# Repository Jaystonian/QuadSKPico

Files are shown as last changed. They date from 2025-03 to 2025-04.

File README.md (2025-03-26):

# **README - QuadSKPico (Open-Source SID Emulation Hardware)**

## **About This Project**

QuadSKpico is an open-source hardware design for a **multi-RP2040-based SID chip emulator**. It is built from the ground up, independent of SIDKick, and aims to provide a **fully open alternative** for C64 audio enthusiasts.

## **Why This Project?**

- **Truly open-source**: Unlike other designs, all schematics and PCB layouts are **fully published**.
- **Expandable & Community-Driven**: Encourages modifications, improvements, and innovations.
- **No artificial restrictions**: Anyone can build, improve, and even sell hardware based on this design.

## **License & Usage**

- This hardware is licensed under the **CERN OHL-S 2.0**, ensuring it remains open and free.
- The firmware it runs is released under **GPLv3**, meaning modifications must also remain open-source.
- This project is **not affiliated with or derived from SIDKick hardware** and the SIDKick Pico software is not compatible.

## **How to Contribute**

Pull requests, hardware modifications, and software contributions are welcome! Feel free to fork, improve, and share your work.

## **Credits**

- Hardware Designed by **JAYSTONIAN**
- Inspired by the open-source hardware movement and the SID emulation community.

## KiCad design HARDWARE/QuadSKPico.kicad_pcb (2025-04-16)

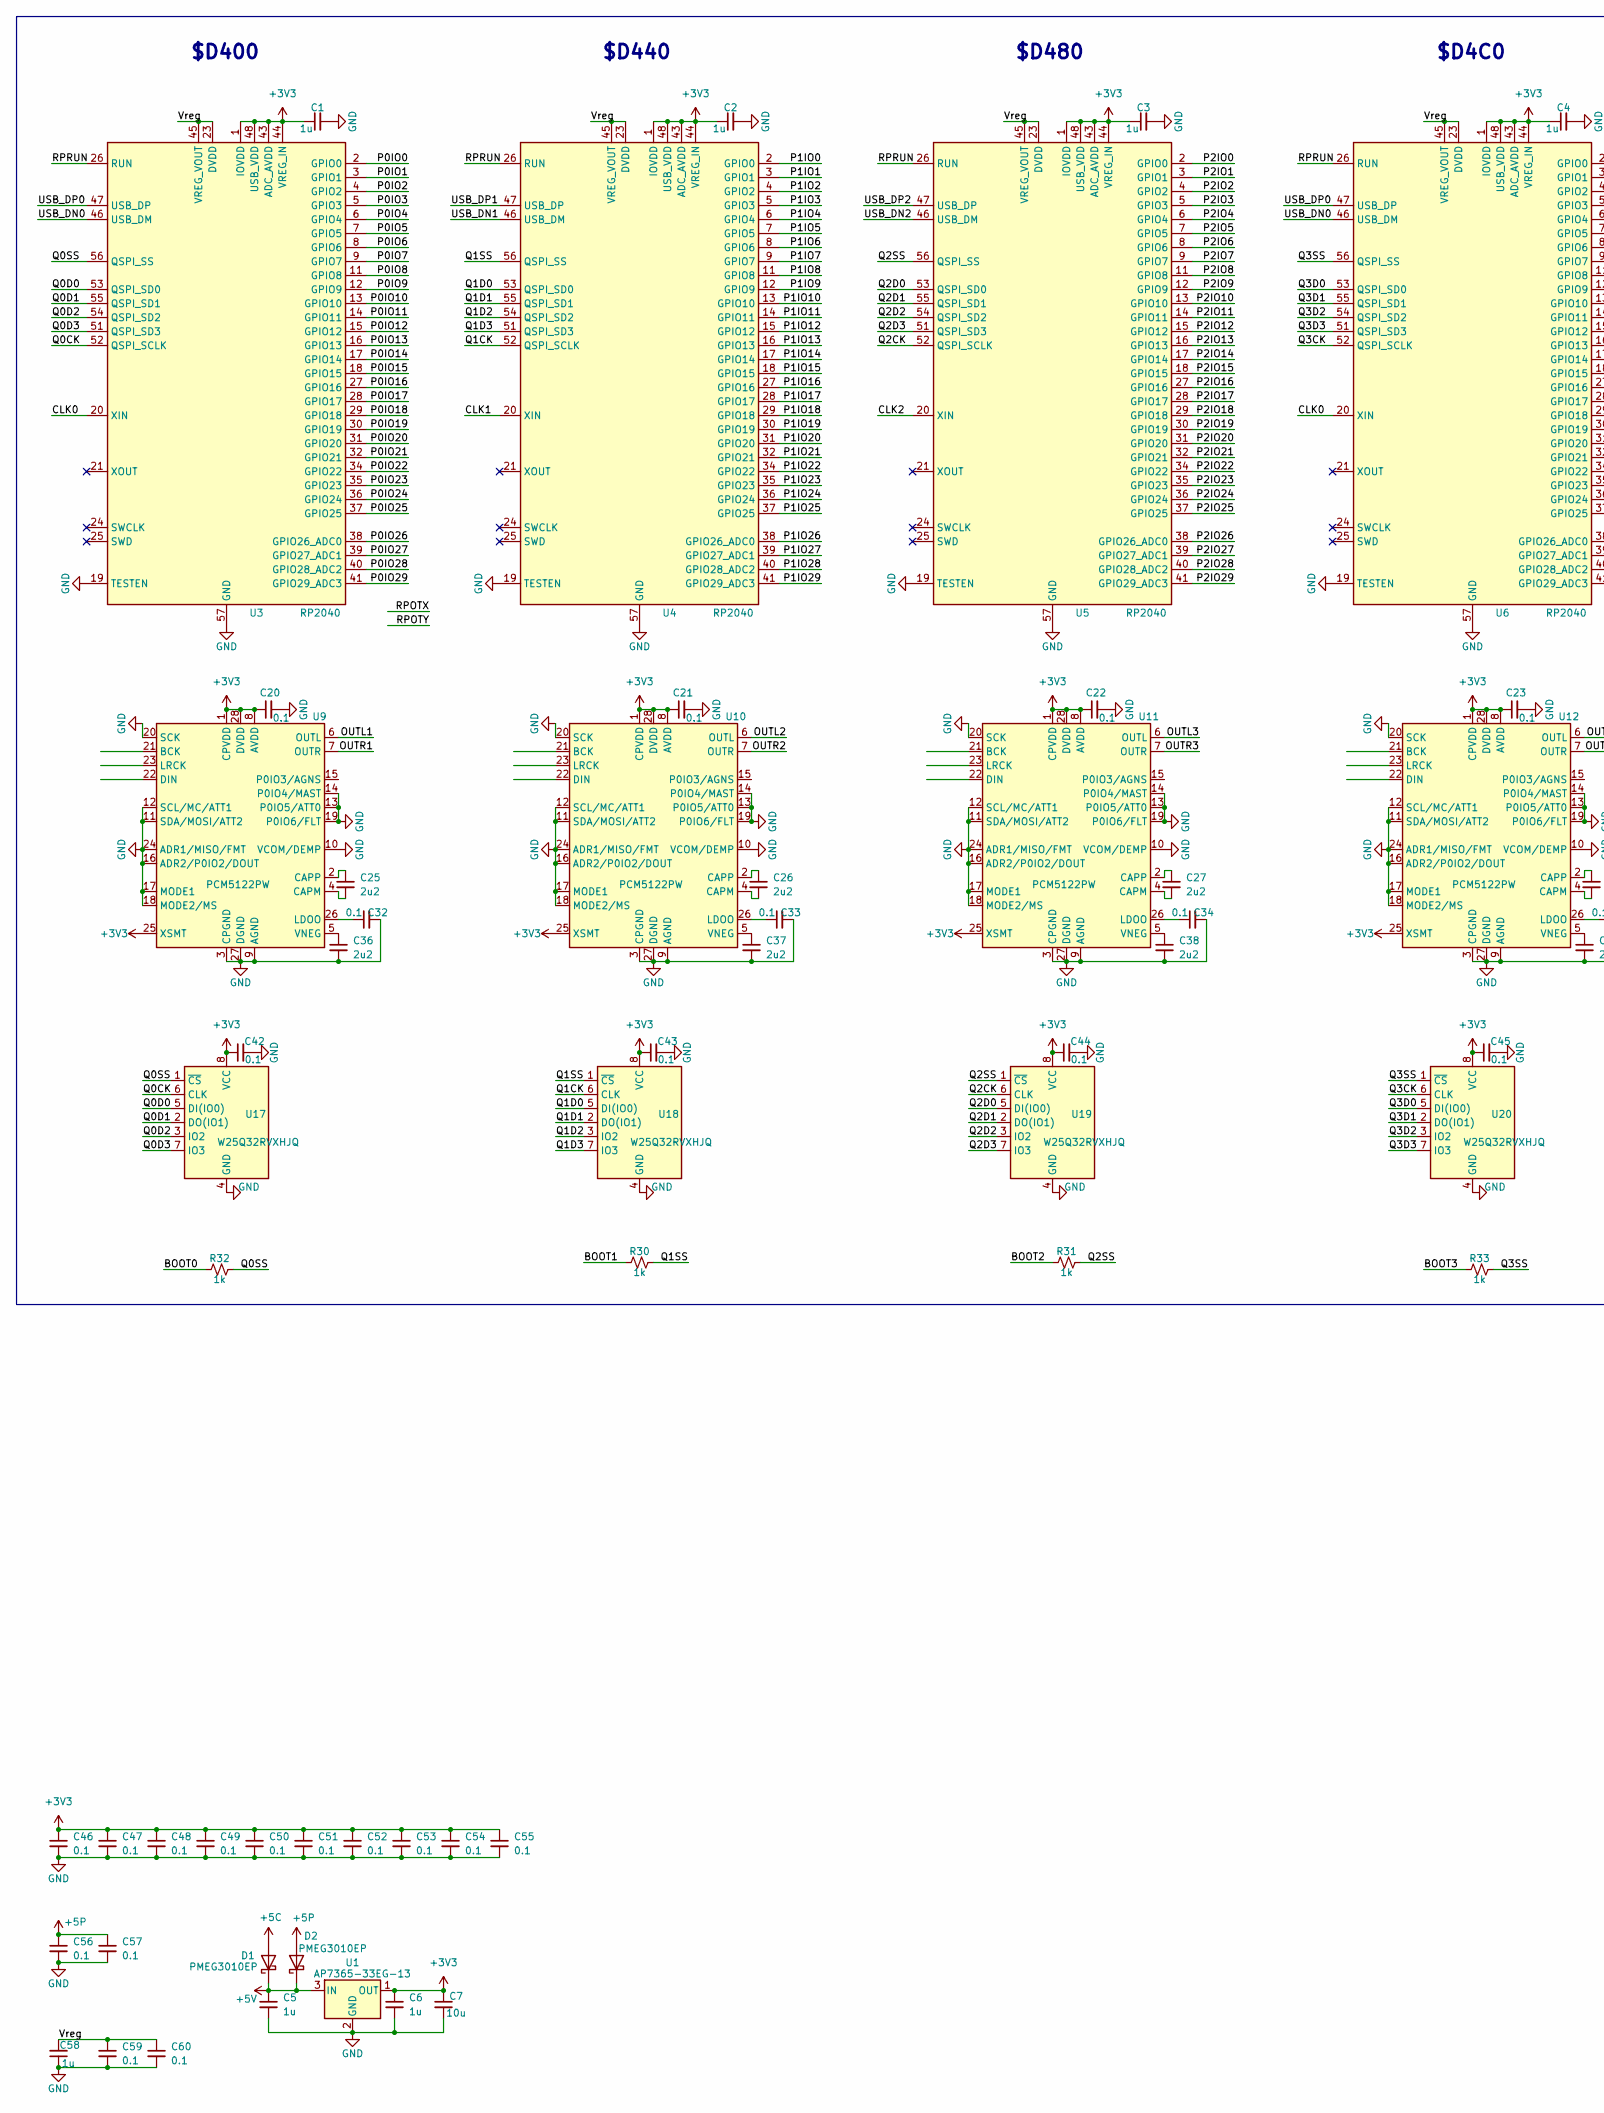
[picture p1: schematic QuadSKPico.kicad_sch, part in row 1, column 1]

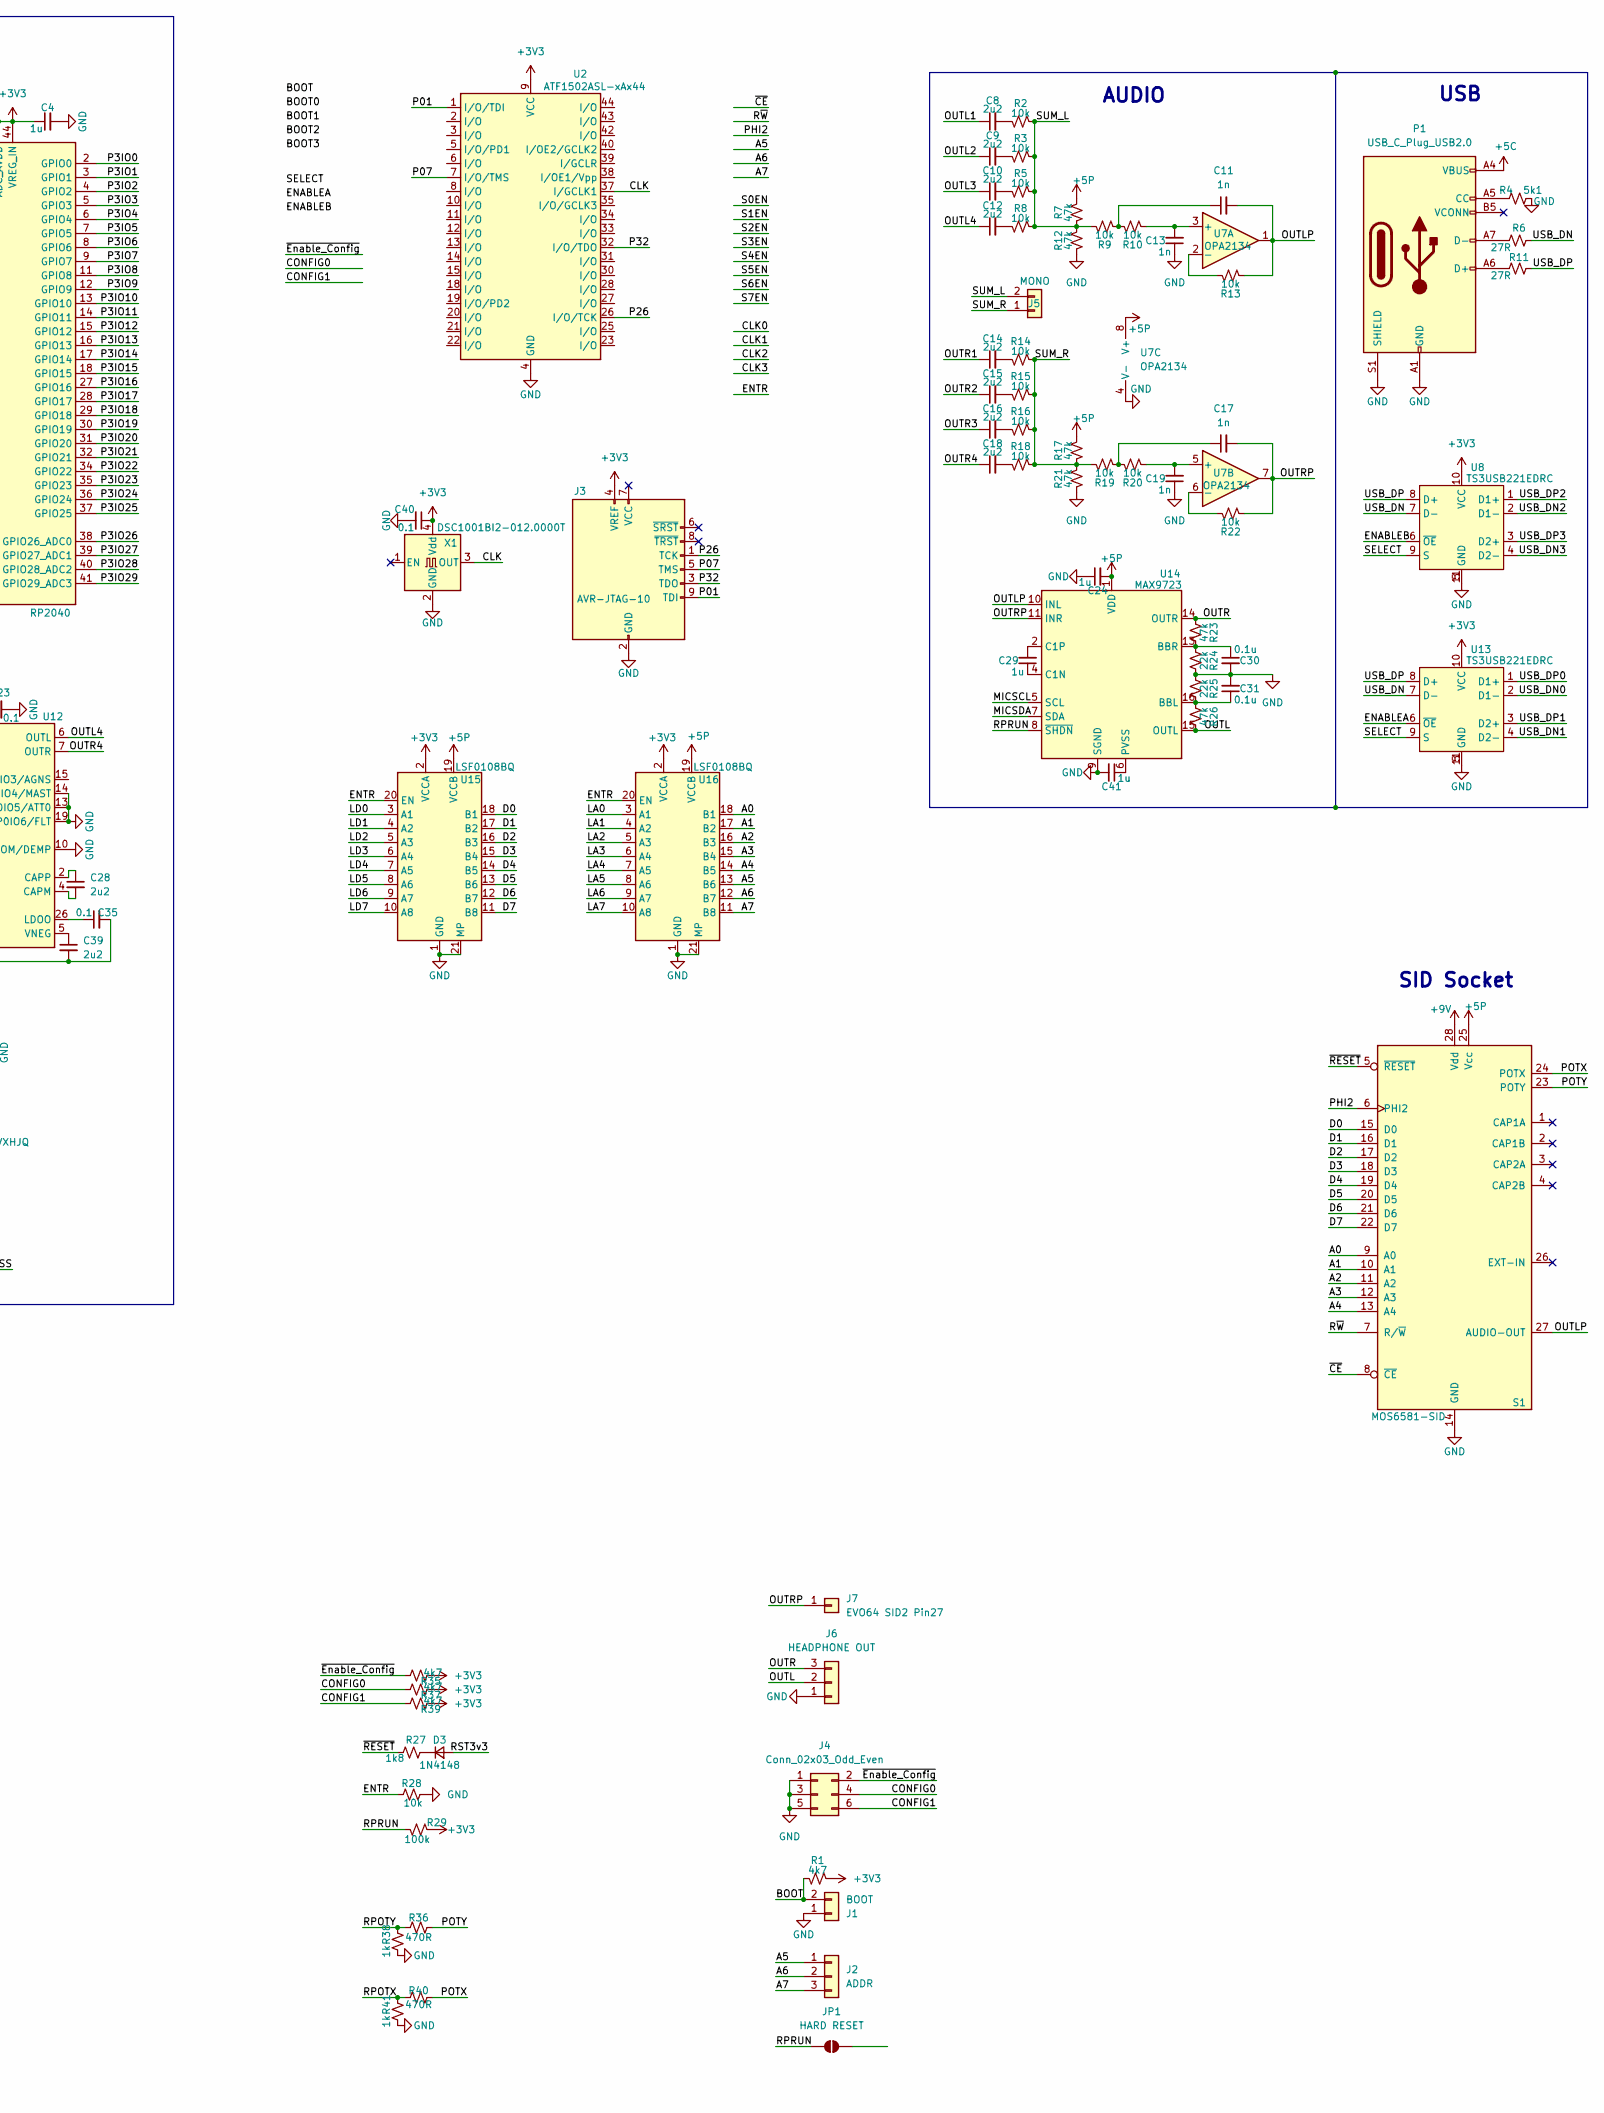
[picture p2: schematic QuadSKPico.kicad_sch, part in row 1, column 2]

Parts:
C1, C2, C3, C4, C5, C6, C24, C29, C41, C58: 1u; C_0805_2012Metric_Pad1.18x1.45mm_HandSolder
C7: 10u; C_0805_2012Metric_Pad1.18x1.45mm_HandSolder
C8, C9, C10, C12, C14, C15, C16, C18, C25, C26, C27, C28, C36, C37, C38, C39: 2u2; C_0805_2012Metric_Pad1.18x1.45mm_HandSolder
C11, C13, C17, C19: 1n; C_0805_2012Metric_Pad1.18x1.45mm_HandSolder
C20, C21, C22, C23, C32, C33, C34, C35, C40, C42, C43, C44, C45, C46, C47, C48, C49, C50, C51, C52, C53, C54, C55, C56, C57, C59, C60: 0.1; C_0805_2012Metric_Pad1.18x1.45mm_HandSolder
C30, C31: 0.1u; C_0805_2012Metric_Pad1.18x1.45mm_HandSolder
D1, D2: PMEG3010EP; D_SMA_Handsoldering
D3: 1N4148; D_MiniMELF
J1: BOOT; PinHeader_1x02_P2.54mm_Vertical
J2: ADDR; PinHeader_1x03_P2.54mm_Vertical
J3: AVR-JTAG-10; PinHeader_2x05_P2.54mm_Vertical
J4: Conn_02x03_Odd_Even; PinHeader_2x03_P2.54mm_Vertical
J5: MONO; PinHeader_1x02_P2.54mm_Vertical
J6: HEADPHONE OUT; PinHeader_1x03_P2.54mm_Vertical
J7: EVO64 SID2 Pin27; PinHeader_1x01_P2.54mm_Vertical
JP1: HARD RESET; SolderJumper-2_P1.3mm_Open_RoundedPad1.0x1.5mm
P1: USB_C_Plug_USB2.0; USB_C_Receptacle_GCT_USB4110
R1, R35, R37, R39: 4k7; C_0805_2012Metric_Pad1.18x1.45mm_HandSolder
R2, R3, R5, R8, R9, R10, R13, R14, R15, R16, R18, R19, R20, R22, R28: 10k; C_0805_2012Metric_Pad1.18x1.45mm_HandSolder
R4: 5k1; C_0805_2012Metric_Pad1.18x1.45mm_HandSolder
R6, R11: 27R; C_0805_2012Metric_Pad1.18x1.45mm_HandSolder
R7, R12, R17, R21, R23, R26: 47k; C_0805_2012Metric_Pad1.18x1.45mm_HandSolder
R24, R25: 22k; C_0805_2012Metric_Pad1.18x1.45mm_HandSolder
R27: 1k8; C_0805_2012Metric_Pad1.18x1.45mm_HandSolder
R29: 100k; C_0805_2012Metric_Pad1.18x1.45mm_HandSolder
R30, R31, R32, R33, R38, R41: 1k; C_0805_2012Metric_Pad1.18x1.45mm_HandSolder
R36, R40: 470R; C_0805_2012Metric_Pad1.18x1.45mm_HandSolder
S1: MOS6581-SID; DIP-28_W15.24mm_Socket
U1: AP7365-33EG-13; SOT-223-3_TabPin2
U2: ATF1502ASL-xAx44; TQFP-44_10x10mm_P0.8mm
U3, U4, U5, U6: RP2040; QFN-56-1EP_7x7mm_P0.4mm_EP3.2x3.2mm
U7: OPA2134; SOIC-8_3.9x4.9mm_P1.27mm
U8, U13: TS3USB221EDRC; VSON-10-1EP_3x3mm_P0.5mm_EP1.65x2.4mm_ThermalVias
U9, U10, U11, U12: PCM5122PW; TSSOP-28_4.4x9.7mm_P0.65mm
U14: MAX9723; TQFN-16-1EP_4x4mm_P0.65mm_EP2.1x2.1mm_ThermalVias
U15, U16: LSF0108BQ; DHVQFN-20-1EP_2.5x4.5mm_P0.5mm_EP1x3mm
U17, U18, U19, U20: W25Q32RVXHJQ; Winbond_USON-8-1EP_3x2mm_P0.5mm_EP0.2x1.6mm
X1: DSC1001BI2-012.0000T; Oscillator_SMD_TXC_7C-4Pin_5.0x3.2mm

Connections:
+3V3: C1.1, C2.1, C3.1, C4.1, C6.1, C7.1, C20.1, C21.1, C22.1, C23.1, C40.1, C42.1, C43.1, C44.1, C45.1, C46.1, C47.1, C48.1, C49.1, C50.1, C51.1, C52.1, C53.1, C54.1, C55.1, J3.4 (VREF), R1.1, R29.1, R35.1, R37.1, R39.1, U1.1 (OUT), U2.9 (VCC), U2.17 (VCC), U2.29 (VCC), U2.41 (VCC), U3.1 (IOVDD), U3.10 (IOVDD), U3.22 (IOVDD), U3.33 (IOVDD), U3.42 (IOVDD), U3.43 (ADC_AVDD), U3.44 (VREG_IN), U3.48 (USB_VDD), U3.49 (IOVDD), U4.1 (IOVDD), U4.10 (IOVDD), U4.22 (IOVDD), U4.33 (IOVDD), U4.42 (IOVDD), U4.43 (ADC_AVDD), U4.44 (VREG_IN), U4.48 (USB_VDD), U4.49 (IOVDD), U5.1 (IOVDD), U5.10 (IOVDD), U5.22 (IOVDD), U5.33 (IOVDD), U5.42 (IOVDD), U5.43 (ADC_AVDD), U5.44 (VREG_IN), U5.48 (USB_VDD), U5.49 (IOVDD), U6.1 (IOVDD), U6.10 (IOVDD), U6.22 (IOVDD), U6.33 (IOVDD), U6.42 (IOVDD), U6.43 (ADC_AVDD), U6.44 (VREG_IN), U6.48 (USB_VDD), U6.49 (IOVDD), U8.10 (VCC), U9.1 (CPVDD), U9.8 (AVDD), U9.25 (XSMT), U9.28 (DVDD), U10.1 (CPVDD), U10.8 (AVDD), U10.25 (XSMT), U10.28 (DVDD), U11.1 (CPVDD), U11.8 (AVDD), U11.25 (XSMT), U11.28 (DVDD), U12.1 (CPVDD), U12.8 (AVDD), U12.25 (XSMT), U12.28 (DVDD), U13.10 (VCC), U15.2 (VCCA), U16.2 (VCCA), U17.8 (VCC), U18.8 (VCC), U19.8 (VCC), U20.8 (VCC), X1.4 (Vdd)
+5C: D1.2 (A), P1.A4 (VBUS), P1.A9 (VBUS), P1.B4 (VBUS), P1.B9 (VBUS)
+5P: C24.2, C56.1, C57.1, D2.2 (A), R7.1, R17.1, S1.25 (Vcc), U7.8 (V+), U14.1 (VDD), U15.19 (VCCB), U16.19 (VCCB)
+5V: C5.1, D1.1 (K), D2.1 (K), U1.3 (IN)
+9V: S1.28 (Vdd)
/A0: S1.9 (A0), U16.18 (B1)
/A1: S1.10 (A1), U16.17 (B2)
/A2: S1.11 (A2), U16.16 (B3)
/A3: S1.12 (A3), U16.15 (B4)
/A4: S1.13 (A4), U16.14 (B5)
/A5: J2.1, U16.13 (B6)
/A6: J2.2, U16.12 (B7)
/A7: J2.3, U16.11 (B8)
/BOOT: J1.2, R1.2
/BOOT0: R32.1
/BOOT1: R30.1
/BOOT2: R31.1
/BOOT3: R33.1
/CLK: U2.37 (I/GCLK1), X1.3 (OUT)
/CLK0: U3.20 (XIN), U6.20 (XIN)
/CLK1: U4.20 (XIN)
/CLK2: U5.20 (XIN)
/CONFIG0: J4.4, R37.2
/CONFIG1: J4.6, R39.2
/D0: S1.15 (D0), U15.18 (B1)
/D1: S1.16 (D1), U15.17 (B2)
/D2: S1.17 (D2), U15.16 (B3)
/D3: S1.18 (D3), U15.15 (B4)
/D4: S1.19 (D4), U15.14 (B5)
/D5: S1.20 (D5), U15.13 (B6)
/D6: S1.21 (D6), U15.12 (B7)
/D7: S1.22 (D7), U15.11 (B8)
/ENABLEA: U13.6 (~OE)
/ENABLEB: U8.6 (~OE)
/ENTR: R28.1, U15.20 (EN), U16.20 (EN)
/LA0: U16.3 (A1)
/LA1: U16.4 (A2)
/LA2: U16.5 (A3)
/LA3: U16.6 (A4)
/LA4: U16.7 (A5)
/LA5: U16.8 (A6)
/LA6: U16.9 (A7)
/LA7: U16.10 (A8)
/LD0: U15.3 (A1)
/LD1: U15.4 (A2)
/LD2: U15.5 (A3)
/LD3: U15.6 (A4)
/LD4: U15.7 (A5)
/LD5: U15.8 (A6)
/LD6: U15.9 (A7)
/LD7: U15.10 (A8)
/MICSCL: U14.5 (SCL)
/MICSDA: U14.7 (SDA)
/OUTL: J6.2, R26.2, U14.15 (OUTL)
/OUTL1: C8.1, U9.6 (OUTL)
/OUTL2: C9.1, U10.6 (OUTL)
/OUTL3: C10.1, U11.6 (OUTL)
/OUTL4: C12.1, U12.6 (OUTL)
/OUTLP: C11.2, R13.2, S1.27 (AUDIO-OUT), U7.1, U14.10 (INL)
/OUTR: J6.3, R23.1, U14.14 (OUTR)
/OUTR1: C14.1, U9.7 (OUTR)
/OUTR2: C15.1, U10.7 (OUTR)
/OUTR3: C16.1, U11.7 (OUTR)
/OUTR4: C18.1, U12.7 (OUTR)
/OUTRP: C17.2, J7.1, R22.2, U7.7, U14.11 (INR)
/P0IO0: U3.2 (GPIO0)
/P0IO1: U3.3 (GPIO1)
/P0IO2: U3.4 (GPIO2)
/P0IO3: U3.5 (GPIO3)
/P0IO4: U3.6 (GPIO4)
/P0IO5: U3.7 (GPIO5)
/P0IO6: U3.8 (GPIO6)
/P0IO7: U3.9 (GPIO7)
/P0IO8: U3.11 (GPIO8)
/P0IO9: U3.12 (GPIO9)
/P0IO10: U3.13 (GPIO10)
/P0IO11: U3.14 (GPIO11)
/P0IO12: U3.15 (GPIO12)
/P0IO13: U3.16 (GPIO13)
/P0IO14: U3.17 (GPIO14)
/P0IO15: U3.18 (GPIO15)
/P0IO16: U3.27 (GPIO16)
/P0IO17: U3.28 (GPIO17)
/P0IO18: U3.29 (GPIO18)
/P0IO19: U3.30 (GPIO19)
/P0IO20: U3.31 (GPIO20)
/P0IO21: U3.32 (GPIO21)
/P0IO22: U3.34 (GPIO22)
/P0IO23: U3.35 (GPIO23)
/P0IO24: U3.36 (GPIO24)
/P0IO25: U3.37 (GPIO25)
/P0IO26: U3.38 (GPIO26_ADC0)
/P0IO27: U3.39 (GPIO27_ADC1)
/P0IO28: U3.40 (GPIO28_ADC2)
/P0IO29: U3.41 (GPIO29_ADC3)
/P01: J3.9 (TDI), U2.1 (I/O/TDI)
/P1IO0: U4.2 (GPIO0)
/P1IO1: U4.3 (GPIO1)
/P1IO2: U4.4 (GPIO2)
/P1IO3: U4.5 (GPIO3)
/P1IO4: U4.6 (GPIO4)
/P1IO5: U4.7 (GPIO5)
/P1IO6: U4.8 (GPIO6)
/P1IO7: U4.9 (GPIO7)
/P1IO8: U4.11 (GPIO8)
/P1IO9: U4.12 (GPIO9)
/P1IO10: U4.13 (GPIO10)
/P1IO11: U4.14 (GPIO11)
/P1IO12: U4.15 (GPIO12)
/P1IO13: U4.16 (GPIO13)
/P1IO14: U4.17 (GPIO14)
/P1IO15: U4.18 (GPIO15)
/P1IO16: U4.27 (GPIO16)
/P1IO17: U4.28 (GPIO17)
/P1IO18: U4.29 (GPIO18)
/P1IO19: U4.30 (GPIO19)
/P1IO20: U4.31 (GPIO20)
/P1IO21: U4.32 (GPIO21)
/P1IO22: U4.34 (GPIO22)
/P1IO23: U4.35 (GPIO23)
/P1IO24: U4.36 (GPIO24)
/P1IO25: U4.37 (GPIO25)
/P1IO26: U4.38 (GPIO26_ADC0)
/P1IO27: U4.39 (GPIO27_ADC1)
/P1IO28: U4.40 (GPIO28_ADC2)
/P1IO29: U4.41 (GPIO29_ADC3)
/P2IO0: U5.2 (GPIO0)
/P2IO1: U5.3 (GPIO1)
/P2IO2: U5.4 (GPIO2)
/P2IO3: U5.5 (GPIO3)
/P2IO4: U5.6 (GPIO4)
/P2IO5: U5.7 (GPIO5)
/P2IO6: U5.8 (GPIO6)
/P2IO7: U5.9 (GPIO7)
/P2IO8: U5.11 (GPIO8)
/P2IO9: U5.12 (GPIO9)
/P2IO10: U5.13 (GPIO10)
/P2IO11: U5.14 (GPIO11)
/P2IO12: U5.15 (GPIO12)
/P2IO13: U5.16 (GPIO13)
/P2IO14: U5.17 (GPIO14)
/P2IO15: U5.18 (GPIO15)
/P2IO16: U5.27 (GPIO16)
/P2IO17: U5.28 (GPIO17)
/P2IO18: U5.29 (GPIO18)
/P2IO19: U5.30 (GPIO19)
/P2IO20: U5.31 (GPIO20)
/P2IO21: U5.32 (GPIO21)
/P2IO22: U5.34 (GPIO22)
/P2IO23: U5.35 (GPIO23)
/P2IO24: U5.36 (GPIO24)
/P2IO25: U5.37 (GPIO25)
/P2IO26: U5.38 (GPIO26_ADC0)
/P2IO27: U5.39 (GPIO27_ADC1)
/P2IO28: U5.40 (GPIO28_ADC2)
/P2IO29: U5.41 (GPIO29_ADC3)
/P3IO0: U6.2 (GPIO0)
/P3IO1: U6.3 (GPIO1)
/P3IO2: U6.4 (GPIO2)
/P3IO3: U6.5 (GPIO3)
/P3IO4: U6.6 (GPIO4)
/P3IO5: U6.7 (GPIO5)
/P3IO6: U6.8 (GPIO6)
/P3IO7: U6.9 (GPIO7)
/P3IO8: U6.11 (GPIO8)
/P3IO9: U6.12 (GPIO9)
/P3IO10: U6.13 (GPIO10)
/P3IO11: U6.14 (GPIO11)
/P3IO12: U6.15 (GPIO12)
/P3IO13: U6.16 (GPIO13)
/P3IO14: U6.17 (GPIO14)
/P3IO15: U6.18 (GPIO15)
/P3IO16: U6.27 (GPIO16)
/P3IO17: U6.28 (GPIO17)
/P3IO18: U6.29 (GPIO18)
/P3IO19: U6.30 (GPIO19)
/P3IO20: U6.31 (GPIO20)
/P3IO21: U6.32 (GPIO21)
/P3IO22: U6.34 (GPIO22)
/P3IO23: U6.35 (GPIO23)
/P3IO24: U6.36 (GPIO24)
/P3IO25: U6.37 (GPIO25)
/P3IO26: U6.38 (GPIO26_ADC0)
/P3IO27: U6.39 (GPIO27_ADC1)
/P3IO28: U6.40 (GPIO28_ADC2)
/P3IO29: U6.41 (GPIO29_ADC3)
/P07: J3.5 (TMS), U2.7 (I/O/TMS)
/P26: J3.1 (TCK), U2.26 (I/O/TCK)
/P32: J3.3 (TDO), U2.32 (I/O/TDO)
/PHI2: S1.6 (PHI2)
/POTX: R40.2, S1.24 (POTX)
/POTY: R36.2, S1.23 (POTY)
/Q0CK: U3.52 (QSPI_SCLK), U17.6 (CLK)
/Q0D0: U3.53 (QSPI_SD0), U17.5 (DI(IO0))
/Q0D1: U3.55 (QSPI_SD1), U17.2 (DO(IO1))
/Q0D2: U3.54 (QSPI_SD2), U17.3 (IO2)
/Q0D3: U3.51 (QSPI_SD3), U17.7 (IO3)
/Q0SS: R32.2, U3.56 (QSPI_SS), U17.1 (~CS)
/Q1CK: U4.52 (QSPI_SCLK), U18.6 (CLK)
/Q1D0: U4.53 (QSPI_SD0), U18.5 (DI(IO0))
/Q1D1: U4.55 (QSPI_SD1), U18.2 (DO(IO1))
/Q1D2: U4.54 (QSPI_SD2), U18.3 (IO2)
/Q1D3: U4.51 (QSPI_SD3), U18.7 (IO3)
/Q1SS: R30.2, U4.56 (QSPI_SS), U18.1 (~CS)
/Q2CK: U5.52 (QSPI_SCLK), U19.6 (CLK)
/Q2D0: U5.53 (QSPI_SD0), U19.5 (DI(IO0))
/Q2D1: U5.55 (QSPI_SD1), U19.2 (DO(IO1))
/Q2D2: U5.54 (QSPI_SD2), U19.3 (IO2)
/Q2D3: U5.51 (QSPI_SD3), U19.7 (IO3)
/Q2SS: R31.2, U5.56 (QSPI_SS), U19.1 (~CS)
/Q3CK: U6.52 (QSPI_SCLK), U20.6 (CLK)
/Q3D0: U6.53 (QSPI_SD0), U20.5 (DI(IO0))
/Q3D1: U6.55 (QSPI_SD1), U20.2 (DO(IO1))
/Q3D2: U6.54 (QSPI_SD2), U20.3 (IO2)
/Q3D3: U6.51 (QSPI_SD3), U20.7 (IO3)
/Q3SS: R33.2, U6.56 (QSPI_SS), U20.1 (~CS)
/RPOTX: R40.1, R41.2
/RPOTY: R36.1, R38.2
/RPRUN: JP1.1 (A), R29.2, U3.26 (RUN), U4.26 (RUN), U5.26 (RUN), U6.26 (RUN), U14.8 (~SHDN)
/RST3v3: D3.2 (A)
/R~W: S1.7 (R/~W)
/SELECT: U8.9 (S), U13.9 (S)
/SUM_L: J5.2, R2.1, R3.1, R5.1, R7.2, R8.1, R9.1, R12.1
/SUM_R: J5.1, R14.1, R15.1, R16.1, R17.2, R18.1, R19.1, R21.1
/USB_DN: R6.2, U8.7 (D-), U13.7 (D-)
/USB_DN0: U3.46 (USB_DM), U6.46 (USB_DM), U13.2 (D1-)
/USB_DN1: U4.46 (USB_DM), U13.4 (D2-)
/USB_DN2: U5.46 (USB_DM), U8.2 (D1-)
/USB_DN3: U8.4 (D2-)
/USB_DP: R11.2, U8.8 (D+), U13.8 (D+)
/USB_DP0: U3.47 (USB_DP), U6.47 (USB_DP), U13.1 (D1+)
/USB_DP1: U4.47 (USB_DP), U13.3 (D2+)
/USB_DP2: U5.47 (USB_DP), U8.1 (D1+)
/USB_DP3: U8.3 (D2+)
/Vreg: C58.2, C59.1, C60.1, U3.23 (DVDD), U3.45 (VREG_VOUT), U3.50 (DVDD), U4.23 (DVDD), U4.45 (VREG_VOUT), U4.50 (DVDD), U5.23 (DVDD), U5.45 (VREG_VOUT), U5.50 (DVDD), U6.23 (DVDD), U6.45 (VREG_VOUT), U6.50 (DVDD)
/~CE: S1.8 (~CE)
/~Enable_Config: J4.2, R35.2
/~RESET: R27.1, S1.5 (~RESET)
GND: C1.2, C2.2, C3.2, C4.2, C5.2, C6.2, C7.2, C13.1, C19.1, C20.2, C21.2, C22.2, C23.2, C24.1, C30.2, C31.2, C32.2, C33.2, C34.2, C35.2, C36.2, C37.2, C38.2, C39.2, C40.2, C41.2, C42.2, C43.2, C44.2, C45.2, C46.2, C47.2, C48.2, C49.2, C50.2, C51.2, C52.2, C53.2, C54.2, C55.2, C56.2, C57.2, C58.1, C59.2, C60.2, J1.1, J3.2 (GND), J3.10 (GND), J4.1, J4.3, J4.5, J6.1, P1.A1 (GND), P1.A12 (GND), P1.B1 (GND), P1.B12 (GND), P1.S1 (SHIELD), R4.2, R12.2, R21.2, R24.2, R25.1, R28.2, R38.1, R41.1, S1.14 (GND), U1.2 (GND), U2.4 (GND), U2.16 (GND), U2.24 (GND), U2.36 (GND), U3.19 (TESTEN), U3.57 (GND), U4.19 (TESTEN), U4.57 (GND), U5.19 (TESTEN), U5.57 (GND), U6.19 (TESTEN), U6.57 (GND), U7.4 (V-), U8.5 (GND), U8.11 (GND), U9.3 (CPGND), U9.9 (AGND), U9.10 (VCOM/DEMP), U9.11 (SDA/MOSI/ATT2), U9.12 (SCL/MC/ATT1), U9.13 (P0IO5/ATT0), U9.14 (P0IO4/MAST), U9.16 (ADR2/P0IO2/DOUT), U9.17 (MODE1), U9.18 (MODE2/MS), U9.19 (P0IO6/FLT), U9.20 (SCK), U9.24 (ADR1/MISO/FMT), U9.27 (DGND), U10.3 (CPGND), U10.9 (AGND), U10.10 (VCOM/DEMP), U10.11 (SDA/MOSI/ATT2), U10.12 (SCL/MC/ATT1), U10.13 (P0IO5/ATT0), U10.14 (P0IO4/MAST), U10.16 (ADR2/P0IO2/DOUT), U10.17 (MODE1), U10.18 (MODE2/MS), U10.19 (P0IO6/FLT), U10.20 (SCK), U10.24 (ADR1/MISO/FMT), U10.27 (DGND), U11.3 (CPGND), U11.9 (AGND), U11.10 (VCOM/DEMP), U11.11 (SDA/MOSI/ATT2), U11.12 (SCL/MC/ATT1), U11.13 (P0IO5/ATT0), U11.14 (P0IO4/MAST), U11.16 (ADR2/P0IO2/DOUT), U11.17 (MODE1), U11.18 (MODE2/MS), U11.19 (P0IO6/FLT), U11.20 (SCK), U11.24 (ADR1/MISO/FMT), U11.27 (DGND), U12.3 (CPGND), U12.9 (AGND), U12.10 (VCOM/DEMP), U12.11 (SDA/MOSI/ATT2), U12.12 (SCL/MC/ATT1), U12.13 (P0IO5/ATT0), U12.14 (P0IO4/MAST), U12.16 (ADR2/P0IO2/DOUT), U12.17 (MODE1), U12.18 (MODE2/MS), U12.19 (P0IO6/FLT), U12.20 (SCK), U12.24 (ADR1/MISO/FMT), U12.27 (DGND), U13.5 (GND), U13.11 (GND), U14.3 (PGND), U14.9 (SGND), U14.EP, U15.1 (GND), U15.21 (MP), U16.1 (GND), U16.21 (MP), U17.4 (GND), U18.4 (GND), U19.4 (GND), U20.4 (GND), X1.2 (GND)
unnamed: C8.2, R2.2
unnamed: C9.2, R3.2
unnamed: C10.2, R5.2
unnamed: C11.1, R9.2, R10.1
unnamed: C12.2, R8.2
unnamed: C14.2, R14.2
unnamed: C15.2, R15.2
unnamed: C16.2, R16.2
unnamed: C17.1, R19.2, R20.1
unnamed: C18.2, R18.2
unnamed: D3.1 (K), R27.2
unnamed: P1.A5 (CC), R4.1
unnamed: P1.A6 (D+), R11.1
unnamed: P1.A7 (D-), R6.1
unnamed: C13.2, R10.2, U7.3 (+)
unnamed: R13.1, U7.2 (-)
unnamed: C19.2, R20.2, U7.5 (+)
unnamed: R22.1, U7.6 (-)
unnamed: C25.2, U9.4 (CAPM)
unnamed: C25.1, U9.2 (CAPP)
unnamed: C32.1, U9.26 (LDOO)
unnamed: C36.1, U9.5 (VNEG)
unnamed: C26.2, U10.4 (CAPM)
unnamed: C26.1, U10.2 (CAPP)
unnamed: C33.1, U10.26 (LDOO)
unnamed: C37.1, U10.5 (VNEG)
unnamed: C27.2, U11.4 (CAPM)
unnamed: C27.1, U11.2 (CAPP)
unnamed: C34.1, U11.26 (LDOO)
unnamed: C38.1, U11.5 (VNEG)
unnamed: C28.2, U12.4 (CAPM)
unnamed: C28.1, U12.2 (CAPP)
unnamed: C35.1, U12.26 (LDOO)
unnamed: C39.1, U12.5 (VNEG)
unnamed: C31.1, R25.2, R26.1, U14.16 (BBL)
unnamed: C30.1, R23.2, R24.1, U14.13 (BBR)
unnamed: C29.1, U14.4 (C1N)
unnamed: C29.2, U14.2 (C1P)
SVSS: C41.1, U14.6 (PVSS), U14.12 (SVSS)

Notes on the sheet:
$D440
$D400
$D4C0
$D480
SID Socket
AUDIO
USB

Board: 2 copper layers, 134 parts (4 on the bottom side), 125 nets, no tracks yet.
